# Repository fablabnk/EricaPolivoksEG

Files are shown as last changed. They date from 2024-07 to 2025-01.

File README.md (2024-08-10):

# Build Notes

- 2N3094 and 2N3096 have been abbreviated to 4 and 6 respectively on silkscreening
- only place NU 39K resistor if requiring -5V ... +5V output on INV EG OUT (presume otherwise get 0-10V)
- TP labels on schematic could actually be test points on the original PCB - check!

# TODO

TODO: check which DPDT footprint and remove "not verified" from layout - waiting on component
DONE: fully double check schematic against original
DONE: check IDC power pins & keying - stripe should be to -12V rail
DONE: check inverting (-) and non-inverting inputs (+) on TL074 in schematic by comparing to pinout
DONE: redo BOM - check we have 2.7k resistor! No, just 2.9K
DONE: are jacks switched/normalled? Yes pin 3 is engaged instead of pin 2 when the jack in unplugged
DONE: do not mix NPN (2N3904) and PNP (2N3906)
DONE: check diameter of radial caps
DONE: removed TP labels from schematic, can only presume they are useless!
DONE: removed pro power features: polyfuses, reverse polarity protection and inductors
DONE: LED orientation check
DONE: replaced R38 with 2,7k resistor. When 2.2 used and EG OUT is connected to certain VCAs, the looping may stop

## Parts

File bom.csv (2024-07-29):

Reference | Value | Have? | Datasheet | Footprint | Qty | DNP
C1,C3,C5,C6 | 0.1uF | Y | ~ | Capacitor_THT:C_Axial_L3.8mm_D2.6mm_P7.50mm_Horizontal | 4
C2,C4 | 47uFx25V | Y | ~ | Capacitor_THT:CP_Radial_D5.0mm_P2.50mm | 2
C7 | 4.7uFx16V | Y | ~ | Capacitor_THT:CP_Radial_D5.0mm_P2.50mm | 1
D1,D2,D3,D4,D5,D6,D7,D8,D12,D13,D14,D15 | 1N4148 | Y | https://assets.nexperia.com/documents/data-sheet/1N4148_1N4448.pdf | Diode_THT:D_DO-35_SOD27_P7.62mm_Horizontal | 12
D11 | GATE DELAY (YELLOW LED) | Y | ~ | PCM_4ms_LED:LED_3mm_C1A2 | 1
D18 | EG OUT (YELLOW LED) | Y | ~ | PCM_4ms_LED:LED_3mm_C1A2 | 1
J1 | GATE IN | Y |  | Library:EighthInch_PJ398SM_3mmNPTH | 1
J2 | INV EG OUT | Y |  | Library:EighthInch_PJ398SM_3mmNPTH | 1
J3 | Eurorack_Power_10pin_Unshrouded | Y |  | Library:IDC-Header_2x05_P2.54mm_Vertical_Euro_Power_Striped | 1
J4 | GATE DELAY OUT | Y |  | Library:EighthInch_PJ398SM_3mmNPTH | 1
J5 | EG OUT | Y |  | Library:EighthInch_PJ398SM_3mmNPTH | 1
Q1,Q2,Q3,Q4,Q5,Q6 | 2N3904 | Y | https://www.onsemi.com/pub/Collateral/2N3903-D.PDF | Package_TO_SOT_THT:TO-92_Inline | 6
Q7,Q8,Q9 | 2N3906 | Y | https://www.onsemi.com/pub/Collateral/2N3906-D.PDF | Package_TO_SOT_THT:TO-92_Inline | 3
R1,R2,R3 | 200 | Y | ~ | Resistor_THT:R_Axial_DIN0207_L6.3mm_D2.5mm_P7.62mm_Horizontal | 3
R4,R8,R16,R28,R33 | 10k |  | ~ | Resistor_THT:R_Axial_DIN0207_L6.3mm_D2.5mm_P7.62mm_Horizontal | 5
R5,R6,R10,R12,R15,R21,R24,R26,R27,R38,R39,R47,R48 | 100k |  | ~ | Resistor_THT:R_Axial_DIN0207_L6.3mm_D2.5mm_P7.62mm_Horizontal | 13
R7,R49 | 560k |  | ~ | Resistor_THT:R_Axial_DIN0207_L6.3mm_D2.5mm_P7.62mm_Horizontal | 2
R9 | 39k |  | ~ | Resistor_THT:R_Axial_DIN0207_L6.3mm_D2.5mm_P7.62mm_Horizontal | 1
R11,R13,R22 | 20k |  | ~ | Resistor_THT:R_Axial_DIN0207_L6.3mm_D2.5mm_P7.62mm_Horizontal | 3
R14,R23 | 5.1k |  | ~ | Resistor_THT:R_Axial_DIN0207_L6.3mm_D2.5mm_P7.62mm_Horizontal | 2
R17,R31 | 2.7k |  | ~ | Resistor_THT:R_Axial_DIN0207_L6.3mm_D2.5mm_P7.62mm_Horizontal | 2
R18 | 15k |  | ~ | Resistor_THT:R_Axial_DIN0207_L6.3mm_D2.5mm_P7.62mm_Horizontal | 1
R19 | 470k |  | ~ | Resistor_THT:R_Axial_DIN0207_L6.3mm_D2.5mm_P7.62mm_Horizontal | 1
R20 | 150k |  | ~ | Resistor_THT:R_Axial_DIN0207_L6.3mm_D2.5mm_P7.62mm_Horizontal | 1
R25 | 1M |  | ~ | Resistor_THT:R_Axial_DIN0207_L6.3mm_D2.5mm_P7.62mm_Horizontal | 1
R29,R42,R50 | 47k |  | ~ | Resistor_THT:R_Axial_DIN0207_L6.3mm_D2.5mm_P7.62mm_Horizontal | 3
R30,R51 | 56k |  | ~ | Resistor_THT:R_Axial_DIN0207_L6.3mm_D2.5mm_P7.62mm_Horizontal | 2
R32 | 1.8k |  | ~ | Resistor_THT:R_Axial_DIN0207_L6.3mm_D2.5mm_P7.62mm_Horizontal | 1
R34 | NU 39K |  | ~ | Resistor_THT:R_Axial_DIN0207_L6.3mm_D2.5mm_P7.62mm_Horizontal | 1
R35,R36 | 33k |  | ~ | Resistor_THT:R_Axial_DIN0207_L6.3mm_D2.5mm_P7.62mm_Horizontal | 2
R37,R41,R44 | 470 |  | ~ | Resistor_THT:R_Axial_DIN0207_L6.3mm_D2.5mm_P7.62mm_Horizontal | 3
R40,R46 | 3.3k |  | ~ | Resistor_THT:R_Axial_DIN0207_L6.3mm_D2.5mm_P7.62mm_Horizontal | 2
R43 | 220k |  | ~ | Resistor_THT:R_Axial_DIN0207_L6.3mm_D2.5mm_P7.62mm_Horizontal | 1
R45 | 22k |  | ~ | Resistor_THT:R_Axial_DIN0207_L6.3mm_D2.5mm_P7.62mm_Horizontal | 1
RV1 | 1M LOG "ATTACK" |  | ~ | Library:Pot_9mm_DShaft_RemovedPins4_5 | 1
RV2 | 1M LOG "DECAY" |  | ~ | Library:Pot_9mm_DShaft_RemovedPins4_5 | 1
RV3 | 1M LOG "RELEASE" |  | ~ | Library:Pot_9mm_DShaft_RemovedPins4_5 | 1
RV4 | 100k LOG "SUSTAIN" |  | ~ | Library:Pot_9mm_DShaft_RemovedPins4_5 | 1
SW1 | SW_DPDT_x2 |  | ~ | PCM_4ms_Switch:Switch_Toggle_DPDT_SubMini | 1
U1 | TL074 |  | http://www.ti.com/lit/ds/symlink/tl071.pdf | Package_DIP:DIP-14_W7.62mm_Socket | 1

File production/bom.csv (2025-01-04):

Designator | Footprint | Quantity | Value | LCSC Part #
C1, C3, C5, C6 | C_Disc_D3.0mm_W1.6mm_P2.50mm | 4 | 0.1uF
C2, C4 | CP_Radial_D5.0mm_P2.50mm | 2 | 47uFx25V
C7 | CP_Radial_D5.0mm_P2.50mm | 1 | 4.7uFx16V
D1, D12, D13, D14, D15, D2, D3, D4, D5, D6, D7, D8 | D_DO-35_SOD27_P7.62mm_Horizontal_Widened_No_K | 12 | 1N4148
D11, D18 | LED_3mm_C1A2 | 2 | LED
J1 | EighthInch_PJ398SM_3mmNPTH | 1 | GATE IN
J2 | EighthInch_PJ398SM_3mmNPTH | 1 | INV EG OUT
J3 | IDC-Header_2x05_P2.54mm_Vertical_Euro_Power_Striped_ThickerText | 1 | Eurorack_Power_10pin_Unshrouded
J4 | EighthInch_PJ398SM_3mmNPTH | 1 | GATE DELAY OUT
J5 | EighthInch_PJ398SM_3mmNPTH | 1 | EG OUT
Q1, Q2, Q3, Q4, Q5, Q6 | TO-92L_Inline_Wider | 6 | 2N3904
Q7, Q8, Q9 | TO-92L_Inline_Wider | 3 | 2N3906
R1, R2, R3 | R_Axial_DIN0204_L3.6mm_D1.6mm_P7.62mm_Horizontal_Widened | 3 | 200
R10, R12, R15, R21, R24, R26, R27, R38, R39, R47, R48, R5, R6 | R_Axial_DIN0204_L3.6mm_D1.6mm_P7.62mm_Horizontal_Widened | 13 | 100k
R11, R13, R22 | R_Axial_DIN0204_L3.6mm_D1.6mm_P7.62mm_Horizontal_Widened | 3 | 20k
R14, R23 | R_Axial_DIN0204_L3.6mm_D1.6mm_P7.62mm_Horizontal_Widened | 2 | 5.1k
R16, R28, R33, R4, R8 | R_Axial_DIN0204_L3.6mm_D1.6mm_P7.62mm_Horizontal_Widened | 5 | 10k
R17, R31 | R_Axial_DIN0204_L3.6mm_D1.6mm_P7.62mm_Horizontal_Widened | 2 | 2.7k
R18 | R_Axial_DIN0204_L3.6mm_D1.6mm_P7.62mm_Horizontal_Widened | 1 | 15k
R19 | R_Axial_DIN0204_L3.6mm_D1.6mm_P7.62mm_Horizontal_Widened | 1 | 470k
R20 | R_Axial_DIN0204_L3.6mm_D1.6mm_P7.62mm_Horizontal_Widened | 1 | 150k
R25 | R_Axial_DIN0204_L3.6mm_D1.6mm_P7.62mm_Horizontal_Widened | 1 | 1M
R29, R42, R50 | R_Axial_DIN0204_L3.6mm_D1.6mm_P7.62mm_Horizontal_Widened | 3 | 47k
R30, R51 | R_Axial_DIN0204_L3.6mm_D1.6mm_P7.62mm_Horizontal_Widened | 2 | 56k
R32 | R_Axial_DIN0204_L3.6mm_D1.6mm_P7.62mm_Horizontal_Widened | 1 | 1.8k
R34 | R_Axial_DIN0204_L3.6mm_D1.6mm_P7.62mm_Horizontal_Widened | 1 | NU 39k
R35, R36 | R_Axial_DIN0204_L3.6mm_D1.6mm_P7.62mm_Horizontal_Widened | 2 | 33k
R37, R41, R44 | R_Axial_DIN0204_L3.6mm_D1.6mm_P7.62mm_Horizontal_Widened | 3 | 470
R40, R46 | R_Axial_DIN0204_L3.6mm_D1.6mm_P7.62mm_Horizontal_Widened | 2 | 3.3k
R43 | R_Axial_DIN0204_L3.6mm_D1.6mm_P7.62mm_Horizontal_Widened | 1 | 220k
R45 | R_Axial_DIN0204_L3.6mm_D1.6mm_P7.62mm_Horizontal_Widened | 1 | 22k
R49, R7 | R_Axial_DIN0204_L3.6mm_D1.6mm_P7.62mm_Horizontal_Widened | 2 | 560k
R9 | R_Axial_DIN0204_L3.6mm_D1.6mm_P7.62mm_Horizontal_Widened | 1 | 39k
RV1, RV2, RV3 | Pot_9mm_DShaft_RemovedPins4_5 | 3 | 1M A
RV4 | Pot_9mm_DShaft_RemovedPins4_5 | 1 | 100k A
SW1 | Switch_Toggle_DPDT_MS202 | 1 | SW_DPDT_x2
U1 | DIP-14_W7.62mm_Socket | 1 | TL074

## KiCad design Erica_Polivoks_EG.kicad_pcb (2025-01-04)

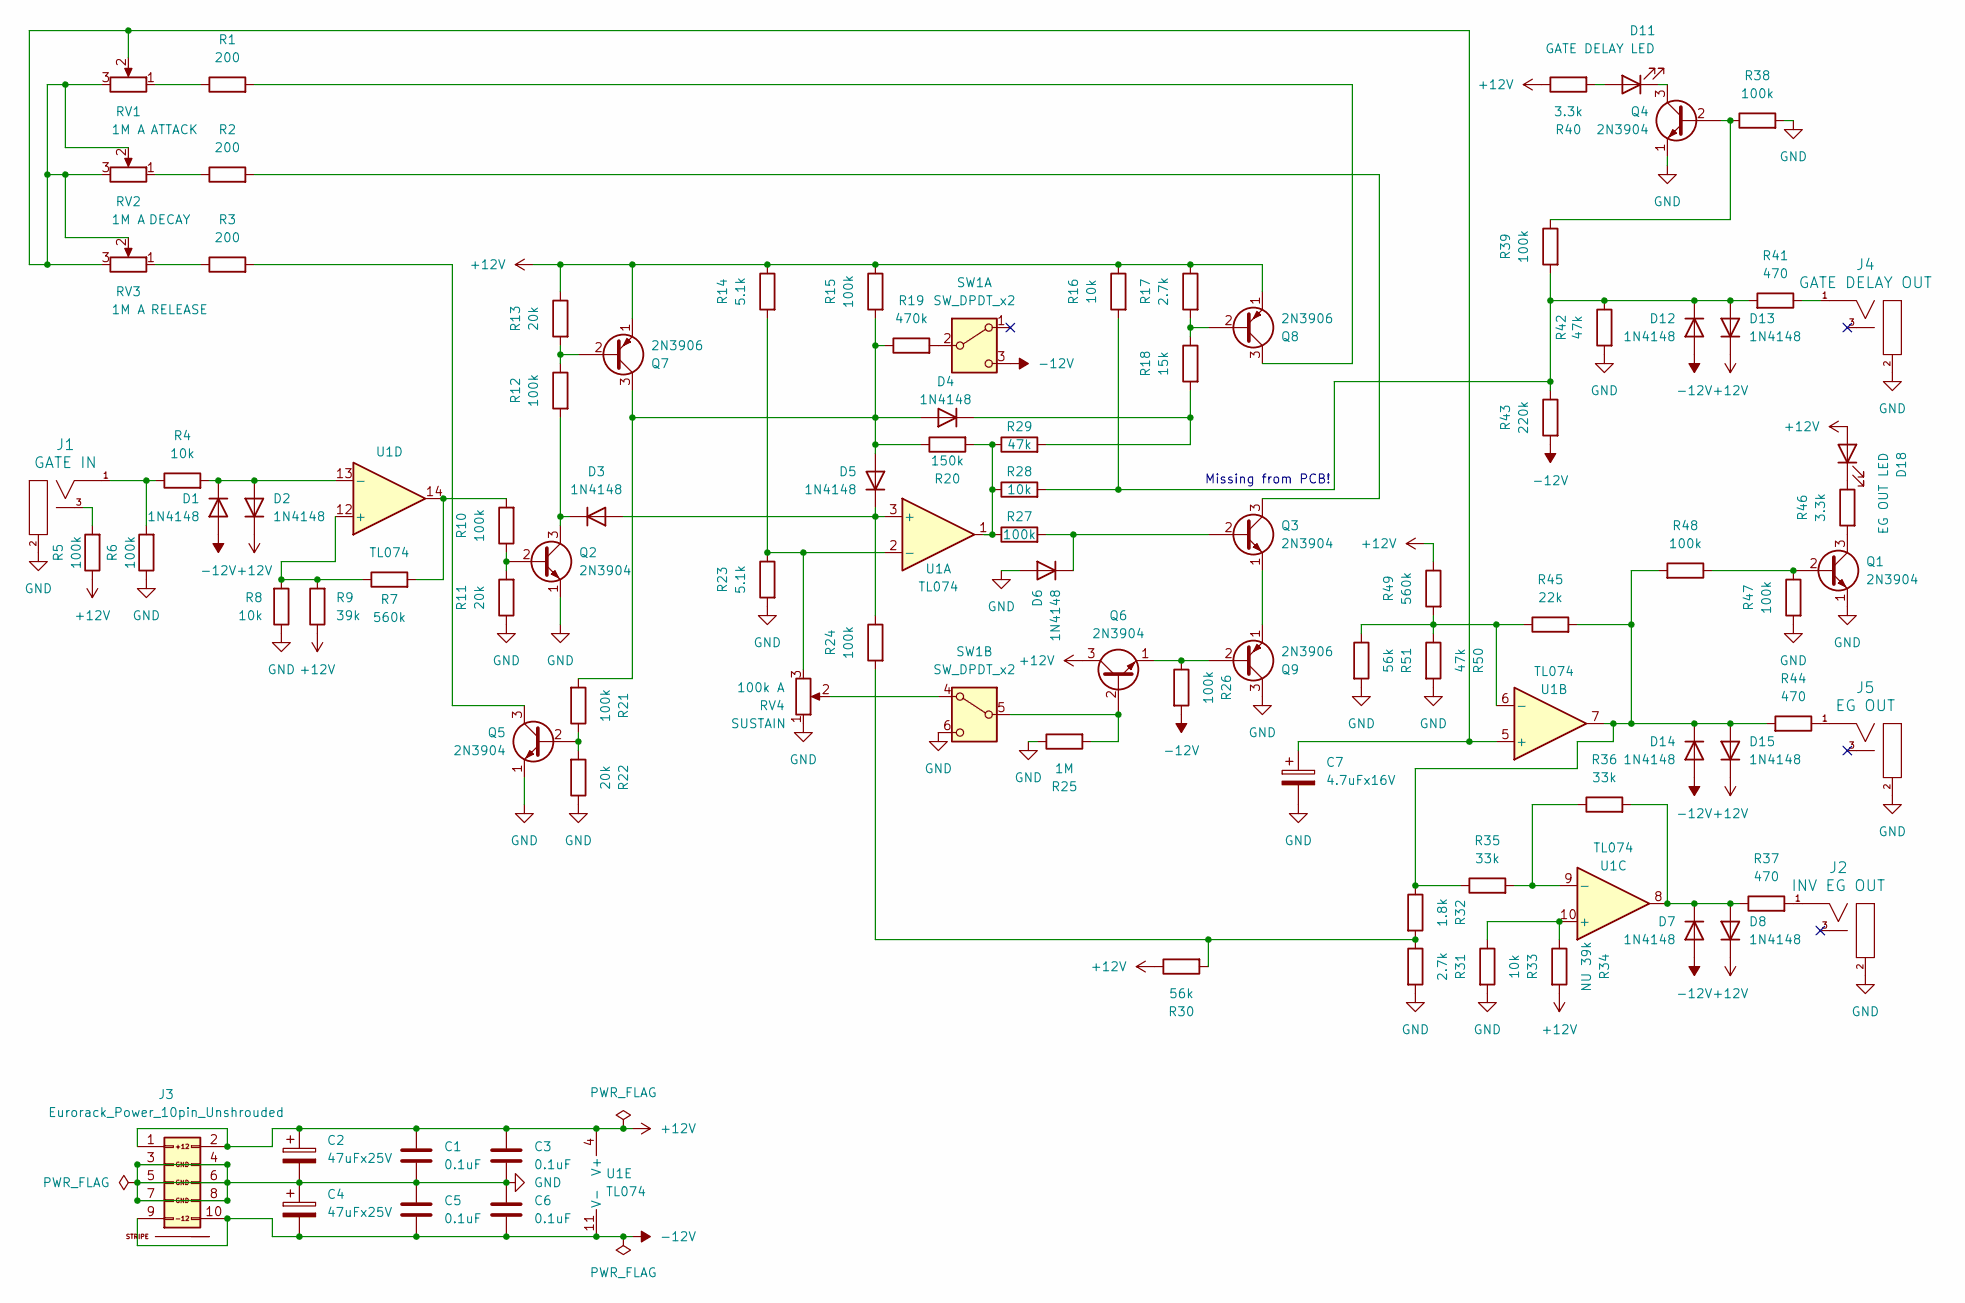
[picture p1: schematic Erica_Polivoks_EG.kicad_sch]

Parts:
C1, C3, C5, C6: 0.1uF; C_Disc_D3.0mm_W1.6mm_P2.50mm
C2, C4: 47uFx25V; CP_Radial_D5.0mm_P2.50mm
C7: 4.7uFx16V; CP_Radial_D5.0mm_P2.50mm
D1, D2, D3, D4, D5, D6, D7, D8, D12, D13, D14, D15: 1N4148; D_DO-35_SOD27_P7.62mm_Horizontal_Widened_No_K
D11, D18: LED; LED_3mm_C1A2
J1: GATE IN; EighthInch_PJ398SM_3mmNPTH; Part Number WQP-WQP518MA
J2: INV EG OUT; EighthInch_PJ398SM_3mmNPTH; Part Number WQP-WQP518MA
J3: Eurorack_Power_10pin_Unshrouded; IDC-Header_2x05_P2.54mm_Vertical_Euro_Power_Striped_Thicker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; Part Number 1-1002FBV0T
J4: GATE DELAY OUT; EighthInch_PJ398SM_3mmNPTH; Part Number WQP-WQP518MA
J5: EG OUT; EighthInch_PJ398SM_3mmNPTH; Part Number WQP-WQP518MA
Q1, Q2, Q3, Q4, Q5, Q6: 2N3904; TO-92L_Inline_Wider
Q7, Q8, Q9: 2N3906; TO-92L_Inline_Wider
R1, R2, R3: 200; R_Axial_DIN0204_L3.6mm_D1.6mm_P7.62mm_Horizontal_Widened
R4, R8, R16, R28, R33: 10k; R_Axial_DIN0204_L3.6mm_D1.6mm_P7.62mm_Horizontal_Widened
R5, R6, R10, R12, R15, R21, R24, R26, R27, R38, R39, R47, R48: 100k; R_Axial_DIN0204_L3.6mm_D1.6mm_P7.62mm_Horizontal_Widened
R7, R49: 560k; R_Axial_DIN0204_L3.6mm_D1.6mm_P7.62mm_Horizontal_Widened
R9: 39k; R_Axial_DIN0204_L3.6mm_D1.6mm_P7.62mm_Horizontal_Widened
R11, R13, R22: 20k; R_Axial_DIN0204_L3.6mm_D1.6mm_P7.62mm_Horizontal_Widened
R14, R23: 5.1k; R_Axial_DIN0204_L3.6mm_D1.6mm_P7.62mm_Horizontal_Widened
R17, R31: 2.7k; R_Axial_DIN0204_L3.6mm_D1.6mm_P7.62mm_Horizontal_Widened
R18: 15k; R_Axial_DIN0204_L3.6mm_D1.6mm_P7.62mm_Horizontal_Widened
R19: 470k; R_Axial_DIN0204_L3.6mm_D1.6mm_P7.62mm_Horizontal_Widened
R20: 150k; R_Axial_DIN0204_L3.6mm_D1.6mm_P7.62mm_Horizontal_Widened
R25: 1M; R_Axial_DIN0204_L3.6mm_D1.6mm_P7.62mm_Horizontal_Widened
R29, R42, R50: 47k; R_Axial_DIN0204_L3.6mm_D1.6mm_P7.62mm_Horizontal_Widened
R30, R51: 56k; R_Axial_DIN0204_L3.6mm_D1.6mm_P7.62mm_Horizontal_Widened
R32: 1.8k; R_Axial_DIN0204_L3.6mm_D1.6mm_P7.62mm_Horizontal_Widened
R34: NU 39k; R_Axial_DIN0204_L3.6mm_D1.6mm_P7.62mm_Horizontal_Widened
R35, R36: 33k; R_Axial_DIN0204_L3.6mm_D1.6mm_P7.62mm_Horizontal_Widened
R37, R41, R44: 470; R_Axial_DIN0204_L3.6mm_D1.6mm_P7.62mm_Horizontal_Widened
R40, R46: 3.3k; R_Axial_DIN0204_L3.6mm_D1.6mm_P7.62mm_Horizontal_Widened
R43: 220k; R_Axial_DIN0204_L3.6mm_D1.6mm_P7.62mm_Horizontal_Widened
R45: 22k; R_Axial_DIN0204_L3.6mm_D1.6mm_P7.62mm_Horizontal_Widened
RV1, RV2, RV3: 1M A; Pot_9mm_DShaft_RemovedPins4_5
RV4: 100k A; Pot_9mm_DShaft_RemovedPins4_5
SW1: SW_DPDT_x2; Switch_Toggle_DPDT_MS202
U1: TL074; DIP-14_W7.62mm_Socket

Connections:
+12V: C1.1, C2.1, C3.1, D2.1 (K), D8.1 (K), D13.1 (K), D15.1 (K), D18.2 (A), J3.1 (+12V), J3.2 (+12V), Q6.3 (C), Q7.1 (E), Q8.1 (E), R5.1, R9.1, R13.1, R14.1, R15.1, R16.1, R17.1, R30.1, R34.2, R40.1, R49.1, U1.4 (V+)
-12V: C4.2, C5.2, C6.2, D1.2 (A), D7.2 (A), D12.2 (A), D14.2 (A), J3.9 (-12V), J3.10 (-12V), R26.2, R43.2, SW1.3 (C), U1.11 (V-)
GND: C1.2, C2.2, C3.2, C4.1, C5.1, C6.1, C7.2, D6.2 (A), J1.2 (SHEILD), J2.2 (SHEILD), J3.3 (GND), J3.4 (GND), J3.5 (GND), J3.6 (GND), J3.7 (GND), J3.8 (GND), J4.2 (SHEILD), J5.2 (SHEILD), Q1.1 (E), Q2.1 (E), Q4.1 (E), Q5.1 (E), Q9.3 (C), R6.1, R8.1, R11.1, R22.1, R23.2, R25.1, R31.2, R33.2, R38.2, R42.2, R47.2, R50.2, R51.2, RV4.1, SW1.6 (C)
unnamed: D1.1 (K), D2.2 (A), R4.2, U1.13 (-)
unnamed: D3.2 (A), D5.1 (K), R24.1, U1.3 (+)
unnamed: D3.1 (K), Q2.3 (C), R12.2
unnamed: D4.2 (A), D5.2 (A), Q7.3 (C), R15.2, R19.1, R20.1, R21.2
unnamed: D4.1 (K), R18.2, R29.2
unnamed: D6.1 (K), Q3.2 (B), R27.2
unnamed: D7.1 (K), D8.2 (A), R36.2, R37.1, U1.8
unnamed: D11.2 (A), R40.2
unnamed: D11.1 (K), Q4.3 (C)
unnamed: D12.1 (K), D13.2 (A), R16.2, R28.2, R39.2, R41.2, R42.1, R43.1
unnamed: D14.1 (K), D15.2 (A), R32.1, R35.1, R44.2, R45.2, R48.2, U1.7
unnamed: D18.1 (K), R46.1
unnamed: J1.1 (SIG), R4.1, R6.2
unnamed: J1.3 (SW), R5.2
unnamed: J2.1 (SIG), R37.2
unnamed: J4.1 (SIG), R41.1
unnamed: J5.1 (SIG), R44.1
unnamed: Q1.2 (B), R47.1, R48.1
unnamed: Q1.3 (C), R46.2
unnamed: Q2.2 (B), R10.1, R11.2
unnamed: Q3.3 (C), R2.2
unnamed: Q3.1 (E), Q9.1 (E)
unnamed: Q4.2 (B), R38.1, R39.1
unnamed: Q5.2 (B), R21.1, R22.2
unnamed: Q5.3 (C), R3.2
unnamed: Q6.2 (B), R25.2, SW1.5 (B)
unnamed: Q6.1 (E), Q9.2 (B), R26.1
unnamed: Q7.2 (B), R12.1, R13.2
unnamed: Q8.2 (B), R17.2, R18.1
unnamed: Q8.3 (C), R1.2
unnamed: R1.1, RV1.1
unnamed: R2.1, RV2.1
unnamed: R3.1, RV3.1
unnamed: R7.2, R10.2, U1.14
unnamed: R20.2, R27.1, R28.1, R29.1, U1.1
unnamed: R24.2, R30.2, R31.1, R32.2
unnamed: R19.2, SW1.2 (B)
unnamed: RV4.2, SW1.4 (A)
unnamed: R14.2, R23.1, RV4.3, U1.2 (-)
unnamed: C7.1, RV1.2, RV1.3, RV2.2, RV2.3, RV3.2, RV3.3, U1.5 (+)
unnamed: R45.1, R49.2, R50.1, R51.1, U1.6 (-)
unnamed: R33.1, R34.1, U1.10 (+)
unnamed: R35.2, R36.1, U1.9 (-)
unnamed: R7.1, R8.2, R9.2, U1.12 (+)

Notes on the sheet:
Missing from PCB!

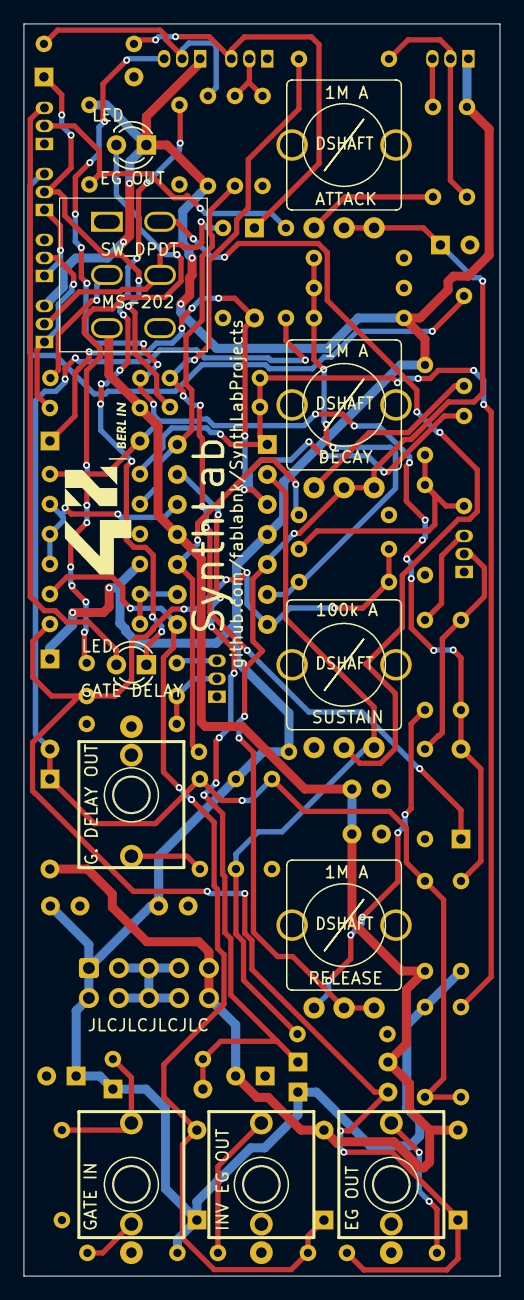
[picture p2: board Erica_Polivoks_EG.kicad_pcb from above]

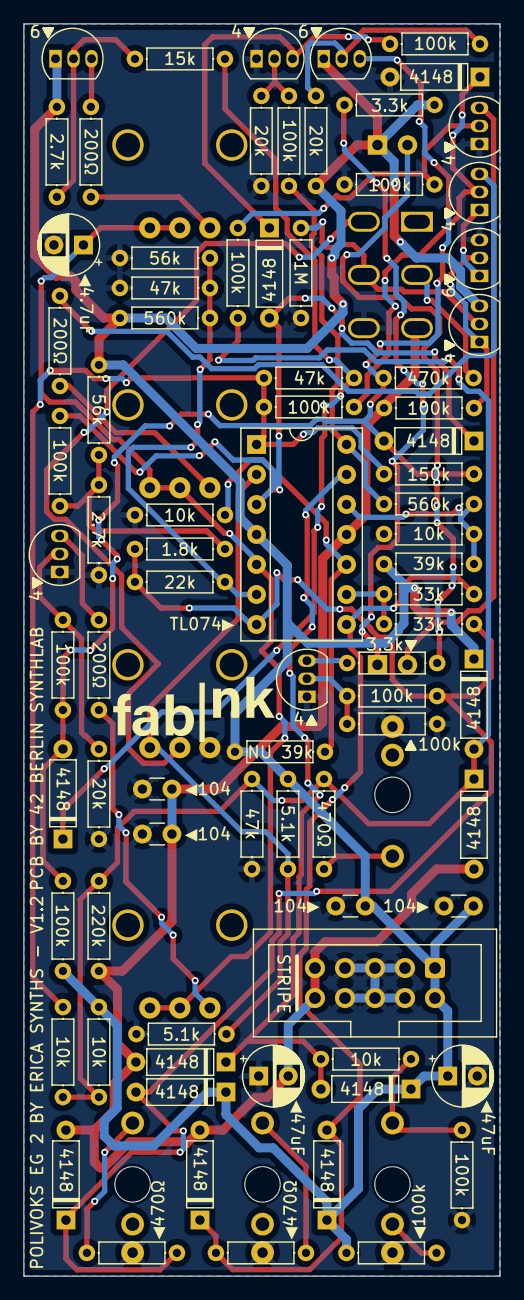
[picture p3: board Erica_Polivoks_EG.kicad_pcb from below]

Board: 2 copper layers, 40.3 x 106.0 mm, 92 parts (81 on the bottom side), 47 nets.

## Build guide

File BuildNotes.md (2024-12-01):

# V1.1

Revised with Dmitri
- update pots
- check out the responses of the curves (oscilloscope)
- why does gate out not work
- why do LED's not work - try it with red ones which demand lower voltage
- Env and Inverse seem to be working

# V1.0

## Things to pay attention to whilst building
- solder "G.Delay Out" jack socket before 100k resistor 
- ms202 switch should probably be wired before 3.3k and 1p0m resistors that are within its footprint
- no need to place 39K resistor marked NU (not used). Placing this resistor would change output from standard 0 to 10V to -5V to 5V (I think...or vice versa?)

## Design issues to fix in V1.1
- FIXED: no components should back onto switch footprint
- FIXED: just put A or B instead of log or lin on pot silkscreening
- FIXED: footprints too wide for 104 caps
- FIXED: TL074 silkscreen text should be outside of footprint so it can be seen after socket is installed
- FIXED: widen switch panel hole to at least 6mm
- IGNORED: could 1K8 resistors go elsewhere? vertical?

## Component issues
- 100k resistors don't even measure close to 100k (80-85) and 560k resistors don't even measure close to 560k. This seems to be down to an issue with lab multimeters. The one with croc clips measures correctly

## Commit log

2024-07-27 initial duplication of the schematic
    [Erica_Polivoks_EG.kicad_pcb, Erica_Polivoks_EG.kicad_sch, bom.csv]
2024-07-27 passed ERC
    [Erica_Polivoks_EG.kicad_sch]
2024-07-27 removed polyfuses, polarity protection diodes and inductors from power section of schematic
    [Erica_Polivoks_EG.kicad_sch]
2024-07-27 schematic double checked
    [Erica_Polivoks_EG.kicad_sch]
2024-07-29 pcb routed
    [Erica_Polivoks_EG.kicad_pcb, Erica_Polivoks_EG.kicad_sch]
2024-07-29 broke panel out into separate PCB file
    [Erica_Polivoks_EG.kicad_pcb, Erica_Polivoks_EG_Panel.kicad_pcb]
2024-07-29 fixed silkscreening issues - just 'not verified' text issue remains
    [Erica_Polivoks_EG.kicad_pcb]
2024-07-29 almost ready to go
    [Erica_Polivoks_EG.kicad_pcb, bom.csv, bom_old.csv]
2024-08-10 waiting for DPDT switch to measure - otherwise complete
    [Erica_Polivoks_EG.kicad_pcb, Erica_Polivoks_EG_Panel.kicad_pcb]
2024-08-13 v1.0 ready for production
    [Erica_Polivoks_EG.kicad_sch, bom-old.csv]
2024-08-15 v1.0 ready for production - added actual HP-size outli]ne on User.Dawings layer
    [Erica_Polivoks_EG.kicad_pcb, Erica_Polivoks_EG.kicad_sch, positions.csv]
2024-09-15 added BuildNotes.md. Removed production folder
    [bom.csv, designators.csv, positions.csv]
2024-09-16 most of V1.1 changes completed
    [Erica_Polivoks_EG.kicad_pcb, Erica_Polivoks_EG.kicad_sch]
2024-09-24 v1.1 ready for final check
    [Erica_Polivoks_EG.kicad_pcb, Erica_Polivoks_EG.kicad_sch]
2025-01-04 rerouting complete and passes DRC
    [Erica_Polivoks_EG.kicad_pcb, Erica_Polivoks_EG.kicad_sch, bom.csv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]
